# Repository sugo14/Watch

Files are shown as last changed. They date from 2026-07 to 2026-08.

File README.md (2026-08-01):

This is one of my first major electronics projects (post-CanSat)!

## Project

The goal of this project is to design a custom smartwatch that fits for my personal use case. That includes:

- Shows the time (obviously)
- Maintains a BLE connection with the associated phone
    - Displays notifications
    - Displays current song playing on Spotify
- Has a push-to-talk mic
    - Streams voice notes to the associated phone, for possible analysis later

## Organization

`mc-screen-breakout` has the first revision of the smartwatch PCB, including the MCU module (containing RF stuff asw), a USB-C port, exposed SWD pins, the screen FPC connector, and the microphone.

`watch` **will** contain iterations of the watch PCB that connect to battery and (theoretically) function properly inside the full system, rather than a breakout.

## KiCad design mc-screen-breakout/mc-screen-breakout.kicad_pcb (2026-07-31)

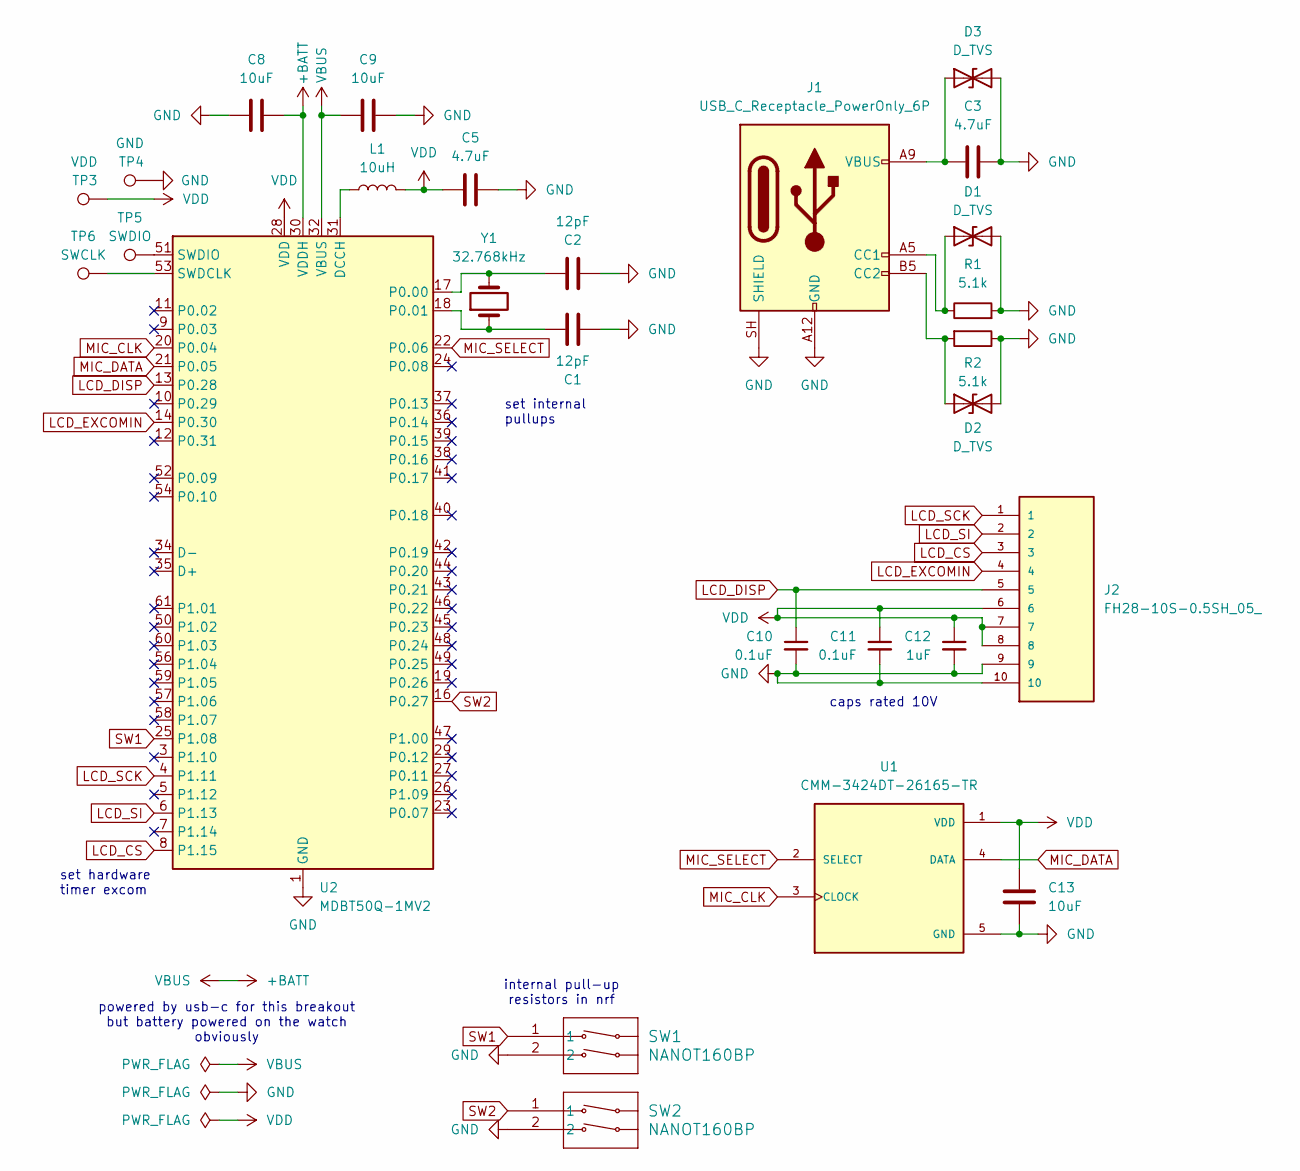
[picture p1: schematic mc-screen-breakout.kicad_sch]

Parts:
C1, C2: 12pF; C_0402_1005Metric
C3, C5: 4.7uF; C_0402_1005Metric
C8, C9, C13: 10uF; C_0402_1005Metric
C10, C11: 0.1uF; C_0402_1005Metric
C12: 1uF; C_0402_1005Metric
D1, D2, D3: D_TVS; D_0402_1005Metric
J1: USB_C_Receptacle_PowerOnly_6P; USB_C_Receptacle_Amphenol_124019772112A
J2: FH28-10S-0.5SH_05_; HIROSE_FH28-10S-0.5SH_05_; PARTREV 13.09.20
L1: 10uH; L_0603_1608Metric
R1, R2: 5.1k; R_0402_1005Metric
SW1, SW2: NANOT160BP; Untitled
TP3: VDD; TestPoint_Pad_1.0x1.0mm
TP4: GND; TestPoint_Pad_1.0x1.0mm
TP5: SWDIO; TestPoint_Pad_1.0x1.0mm
TP6: SWCLK; TestPoint_Pad_1.0x1.0mm
U1: CMM-3424DT-26165-TR; MIC_CMM-3424DT-26165-TR; PARTREV 1.0
U2: MDBT50Q-1MV2; Raytac_MDBT50Q
Y1: 32.768kHz; Crystal_SMD_3215-2Pin_3.2x1.5mm

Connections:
+BATT: C8.1, C9.1, U2.30 (VDDH), U2.32 (VBUS)
GND: C1.1, C2.2, C3.2, C5.2, C8.2, C9.2, C10.2, C11.2, C12.2, C13.2, D1.2 (A2), D2.2 (A2), D3.2 (A2), J1.A12 (GND), J1.B12 (GND), J1.SH (SHIELD), J2.9, J2.10, R1.2, R2.1, SW1.2, SW2.2, TP4.1 (1_1), U1.5 (GND), U1.6 (GND), U1.7 (GND), U1.8 (GND), U2.1 (GND), U2.2 (GND), U2.15 (GND), U2.33 (GND), U2.55 (GND)
LCD_CS: J2.3, U2.8 (P1.15)
LCD_DISP: C10.1, J2.5, U2.13 (P0.28)
LCD_EXCOMIN: J2.4, U2.14 (P0.30)
LCD_SCK: J2.1, U2.4 (P1.11)
LCD_SI: J2.2, U2.6 (P1.13)
MIC_CLK: U1.3 (CLOCK), U2.20 (P0.04)
MIC_DATA: U1.4 (DATA), U2.21 (P0.05)
MIC_SELECT: U1.2 (SELECT), U2.22 (P0.06)
unnamed: D1.1 (A1), J1.A5 (CC1), R1.1
unnamed: D2.1 (A1), J1.B5 (CC2), R2.2
unnamed: C3.1, D3.1 (A1), J1.A9 (VBUS), J1.B9 (VBUS)
unnamed: L1.1, U2.31 (DCCH)
unnamed: C2.1, U2.17 (P0.00), Y1.2
unnamed: C1.2, U2.18 (P0.01), Y1.1
unnamed: TP6.1 (1_1), U2.53 (SWDCLK)
unnamed: TP5.1 (1_1), U2.51 (SWDIO)
SW1: SW1.1, U2.25 (P1.08)
SW2: SW2.1, U2.16 (P0.27)
VDD: C5.1, C11.1, C12.1, C13.1, J2.6, J2.7, J2.8, L1.2, TP3.1 (1_1), U1.1 (VDD), U2.28 (VDD)

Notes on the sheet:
powered by usb-c for this breakout but battery powered on the watch obviously
set internal pullups
caps rated 10V
set hardware timer excom
internal pull-up resistors in nrf

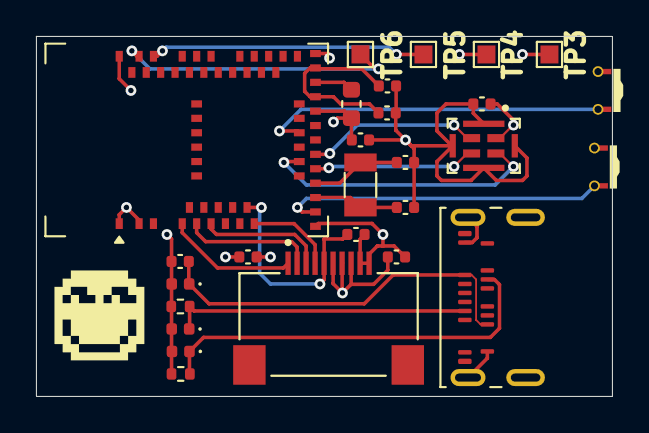
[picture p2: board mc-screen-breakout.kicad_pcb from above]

Board: 4 copper layers, 32.0 x 20.0 mm, 27 parts (0 on the bottom side), 21 nets.

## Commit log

2026-07-15 Reorganized and started breakout
    [mc-screen-breakout.kicad_pcb, mc-screen-breakout.kicad_sch, watch.kicad_pcb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]
2026-07-15 Initial microcontroller power on breakout
    [mc-screen-breakout.kicad_sch]
2026-07-20 Switched to new Raytac module
    [mc-screen-breakout.kicad_sch]
2026-07-21 Added LCD FPC female connector
    [mc-screen-breakout.kicad_sch]
2026-07-21 Added missing decoupling caps
    [mc-screen-breakout.kicad_sch]
2026-07-25 Added mic and switches
    [mc-screen-breakout.kicad_sch]
2026-07-28 Schematic fixes and started routing
    [mc-screen-breakout.kicad_pcb, mc-screen-breakout.kicad_sch]
2026-07-28 Began drawing traces
    [mc-screen-breakout.kicad_pcb, mc-screen-breakout.kicad_sch]
2026-07-28 More routing
    [mc-screen-breakout.kicad_pcb, mc-screen-breakout.kicad_sch]
2026-07-28 Initial routing almost done
    [mc-screen-breakout.kicad_pcb]
2026-07-29 Fixed DRC errors/warnings
    [mc-screen-breakout.kicad_pcb]
2026-07-31 Drew custom switch footprint
    [mc-screen-breakout.kicad_pcb, mc-screen-breakout.kicad_sch]
